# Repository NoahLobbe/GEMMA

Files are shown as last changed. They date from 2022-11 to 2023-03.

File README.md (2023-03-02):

# GEMMA
Gecko Electro-Mechanical Motion Attraction (or just 'Gecko')

This project was made for a robotics course, and is posted here as more of an archive so some stuff might not even work. Originally I designed it to have electromagnets in the ends of the legs powered by a L298N motor driver, but I ended up having to trash that idea; the L298N mounting is still present in final prototype though.

I have included .stl, .f3d (Fusion 360), and .ino (Arduino) files and also a short .pdf outlining its basic operation.

Youtube video: https://www.youtube.com/watch?v=VduDyxTGmJU

## Materials/Components:
- 3D print filament for body
- super glue (or equivalent) for battery packs and servo horns
- Lots of wires
- PCB 
- DC Barrel jack
- 5V regulator for power supply
- Female and Male headers
- 2 AA battery packs
- Arduino Uno
- 4 servos (SG90) (with accompanying servo horns)
- Ultrasonic sensor

### Code Note(s)
Smoothing code for servos I found from **James Bruton**:
- https://www.youtube.com/watch?v=jsXolwJskKM
- https://github.com/XRobots/ServoSmoothing

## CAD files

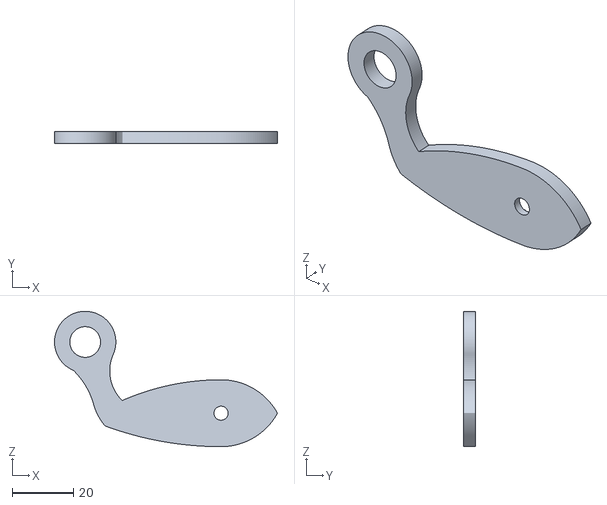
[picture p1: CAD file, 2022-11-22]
STLs/Leg - Right.stl
72.7 x 4.00 x 44.1

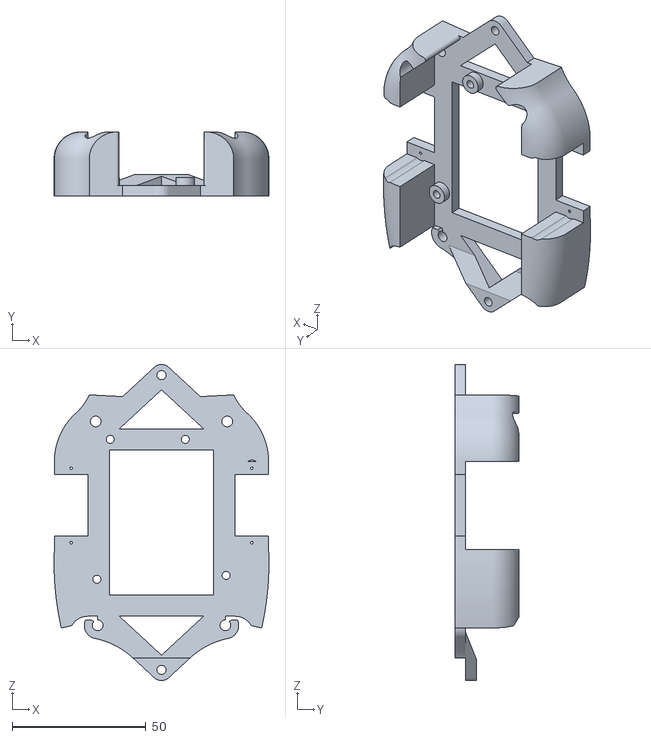
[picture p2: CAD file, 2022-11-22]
STLs/Arduino Base.stl
80.2 x 24.0 x 118.0

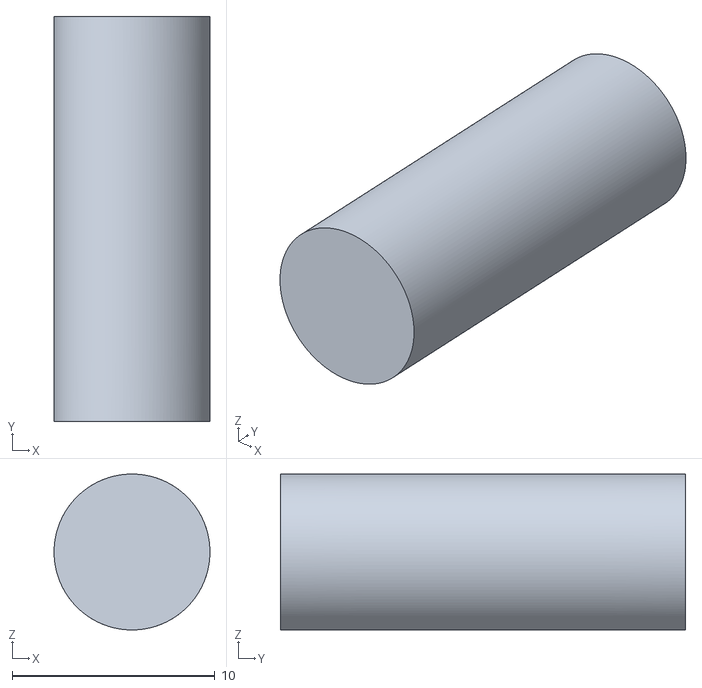
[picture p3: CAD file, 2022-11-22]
STLs/Head Pin.stl
7.70 x 20.0 x 7.70

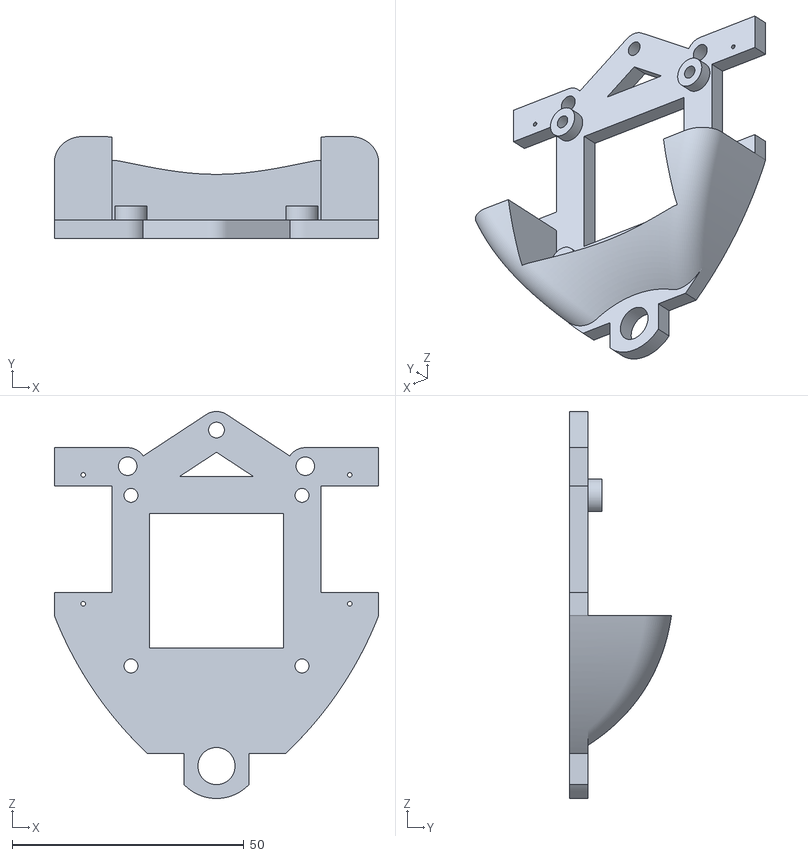
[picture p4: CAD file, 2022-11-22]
STLs/L298N Base.stl
70.0 x 22.0 x 83.5

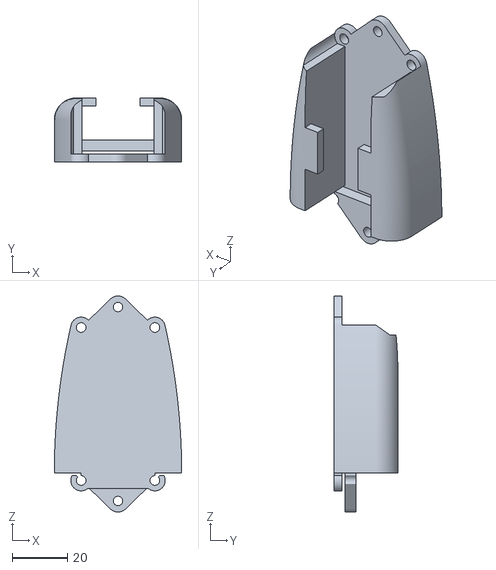
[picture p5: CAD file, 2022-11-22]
STLs/Tail (9V holder).stl
46.0 x 23.2 x 78.0

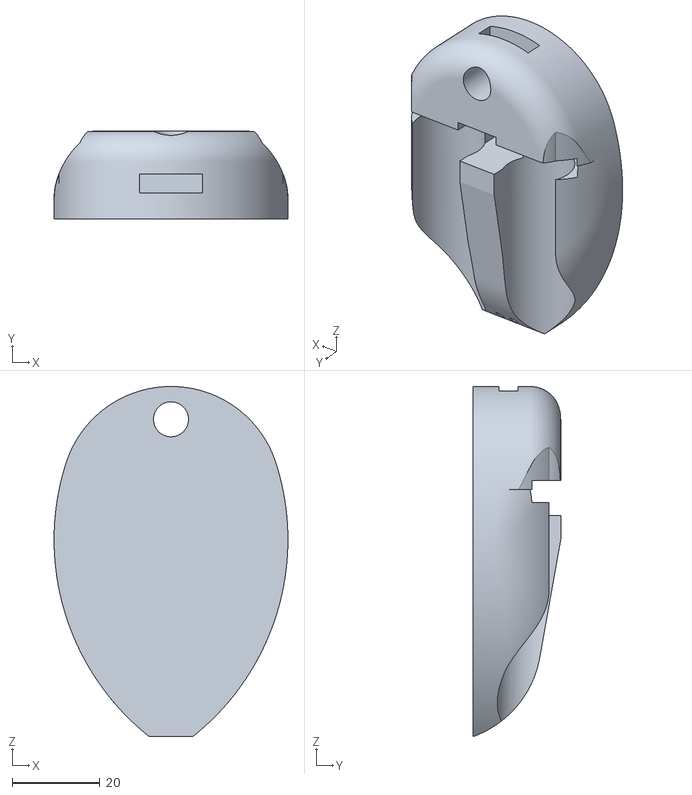
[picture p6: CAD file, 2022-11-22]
STLs/Head.stl
53.5 x 20.0 x 80.0

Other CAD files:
STLs/Leg - Left.stl
CAD/Arduino Base.f3d
CAD/Gecko - Major Product v35.f3z
CAD/Head Pin.f3d
CAD/Head.f3d
CAD/L298N Base.f3d
CAD/Leg - Left.f3d
CAD/Leg - Right.f3d
CAD/Tail (9V holder).f3d

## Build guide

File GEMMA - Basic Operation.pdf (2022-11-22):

# GEMMA

## Gecko Electro-Mechanical Motion Attraction

Made by Noah Lobbe for Stage 1 Robotic and Electronic Systems (Mechatronics)

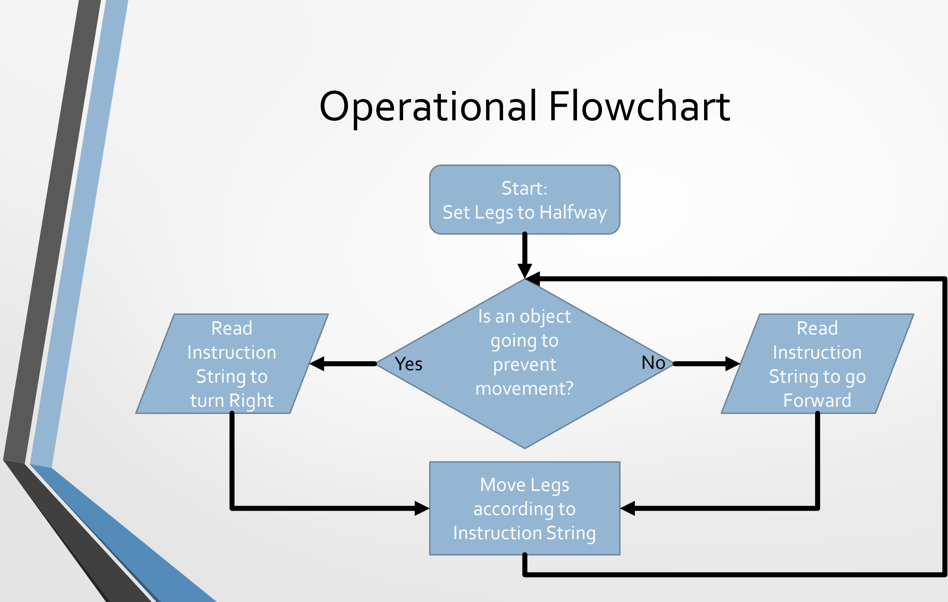
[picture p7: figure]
Operational Flowchart; Start: Set Legs to Halfway; Read Instruction String to go Forward; Is an object going to prevent movement?; Read Instruction String to turn Right; Move Legs according to Instruction String; Yes

# The Instruction String

## Each run through the flowchart, the Arduino reads 3 characters from a string in its code, which tells GEMMA what to do. The Instruction String for forward motion broken into 3-character chunks is: AGD LLU URU ULU AGD LRU ULU …which can be deciphered with the table of codes below:

Direction Code Letters | Group Leg Codes | Individual Leg Codes
U | Up | AGX | All Go X | LLX | LowerLeft go X
H | Halfway | FGX | Front Go X | LRX | LowerRight go X
D | Down | BGX | Back Go X | URX | UpperRight go X
| | LGX | Left Go X | ULX | UpperLeft go X
| | RGX | Right Go X
| | E.g., RGH = Right legs go Halfway | | E.g., URD = Upper Right leg go Down

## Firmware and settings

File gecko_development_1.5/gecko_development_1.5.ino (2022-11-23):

/*
 * GEMMA: Gecko Electro Mechanical Motion Atraction
 * 
 * ----Conventions----
 * constants: 'ALL_CAPS'
 * variables and class members: 'helpful_variable_name'
 * class names and objects: 'DoomButton' or 'Cheese'
 * 
 * by Noah Lobbe 
 * 
 * NOTES:
 * Thanks to James Bruton for his servo smoothing code: https://github.com/XRobots/ServoSmoothing and https://www.youtube.com/watch?v=jsXolwJskKM
 */

#include <Servo.h>


struct Limb {
  Servo Joint;
  float smoothed_angle;
  float prev_smoothed_angle;
  bool move_flag = true;
  char stage_flag = 'U'; //U=up, D=down, E=electromagnet, W=wait
};



////timing for main loop
unsigned long currentMillis;
long previousMillis = 0;    // set up timers
long interval = 5;        //ms time constant for timer


////Motion
 /* 3 letter motion commands
  * AGX = All Go X
  * FGX = Front Go X
  * BGX = Back Go X
  * LGX = Left Go X
  * RGX = Right Go X
  * 
  * DLX = Diagonal Left (\) Go X 
  * DRX = Diagonal Right (/) Go X
  * 
  * XXU = Up
  * XXH = Halfway
  * XXD = Down
  * 
  * LLX = LowerLeft go X
  * LRX = LowerRight go X
  * URX = UpperRight go X
  * ULX = UpperLeft go X
  */

const char straight_motion_array[] = { //best straight line 
  'A', 'G', 'D', 
  'L', 'L', 'U',
  'U', 'R', 'U',
  'U', 'L', 'U',
  'A', 'G', 'D',
  'L', 'R', 'U',
  'U', 'R', 'U',
  'U', 'L', 'U'
};

const char left_turn_motion_array[] = { //not currently used
  'A', 'G', 'D',
  'L', 'R', 'U',
  'U', 'R', 'U',
  'L', 'L', 'U'
};
const char right_turn_motion_array[] = { 
  'A', 'G', 'D',
  'L', 'L', 'U',
  'U', 'L', 'U',
  'L', 'R', 'U'
};

#define STRAIGHT_MOTION_LENGTH sizeof(straight_motion_array)/sizeof(straight_motion_array[0])
#define LEFT_TURN_MOTION_LENGTH sizeof(left_turn_motion_array)/sizeof(left_turn_motion_array[0])
#define RIGHT_TURN_MOTION_LENGTH sizeof(right_turn_motion_array)/sizeof(right_turn_motion_array[0])
int start_slice_index = 0;
int previous_start_slice_index = start_slice_index-1; //mustn't start the same as start_slice_index

String direction_flag = "FORWARD";
char limb_group; //eg AG = All legs
char limb_side; //eg LG = Left legs
char leg_direction; //eg AGU = 
String double_char_code; //becomes (String)limb_group + (String)limb_side; //cast chars to strings to prevent integer addition


////Servos variables and objects
//NOTE: position measurements are not neccessarily degrees, eg. 90 is half way for ServoObj.write(...) method even if a servo can only go to 80deg
#define SERVO_STARTING_POS 90 

//Lower Left Limb
#define SERVO_LL_MIN 30
#define SERVO_LL_MAX 140
#define SERVO_LL_HALF (SERVO_LL_MAX - SERVO_LL_MIN)/2
#define LOWER_LEFT_SERVO_PIN 2
#define LOWER_LEFT_EM_PIN 6 //L298N En_A -> Out_1
Limb LowerLeft;
int16_t servo_angle_input = SERVO_STARTING_POS;

//Lower Right Limb
#define SERVO_LR_MIN 155
#define SERVO_LR_MAX 45
#define SERVO_LR_HALF abs( (SERVO_LR_MAX - SERVO_LR_MIN)/2 )
#define LOWER_RIGHT_SERVO_PIN 3
#define LOWER_RIGHT_EM_PIN 7 //L298N En_B -> Out_2
Limb LowerRight;

//Upper Right Limb
#define SERVO_UR_MIN 125
#define SERVO_UR_MAX 20
#define SERVO_UR_HALF abs( (SERVO_UR_MAX - SERVO_UR_MIN)/2 )
#define UPPER_RIGHT_SERVO_PIN 4
#define UPPER_RIGHT_EM_PIN 8 //L298N En_C -> Out_3
Limb UpperRight;

//Upper Left Limb
#define SERVO_UL_MIN 40
#define SERVO_UL_MAX 130
#define SERVO_UL_HALF (SERVO_UL_MAX - SERVO_UL_MIN)/2
#define UPPER_LEFT_SERVO_PIN 5
#define UPPER_LEFT_EM_PIN 9 //L298N En_D -> Out_4
Limb UpperLeft;


////Ultrasonic sensor
#define TRIGGER 11
#define ECHO  12
#define speed_of_sound 340 //metres per second
uint8_t dist_sensor_time_counter = 0;

#define obstacle_distance_minimum 100 //mm
uint16_t obstacle_distance_mm;



void setup() {

  pinMode(TRIGGER, OUTPUT);
  pinMode(ECHO, INPUT);
  digitalWrite(TRIGGER, LOW);
  
  LowerLeft.Joint.attach(LOWER_LEFT_SERVO_PIN);
  LowerLeft.Joint.write(SERVO_STARTING_POS);//SERVO_LL_MIN);//
  LowerLeft.smoothed_angle = SERVO_STARTING_POS;
  LowerLeft.prev_smoothed_angle = LowerLeft.smoothed_angle; //to prevent leg from going down instantly
  
  LowerRight.Joint.attach(LOWER_RIGHT_SERVO_PIN);
  LowerRight.Joint.write(SERVO_STARTING_POS);
  LowerRight.smoothed_angle = SERVO_STARTING_POS;
  LowerRight.prev_smoothed_angle = LowerRight.smoothed_angle; //to prevent leg from going down instantly

  UpperRight.Joint.attach(UPPER_RIGHT_SERVO_PIN);
  UpperRight.Joint.write(SERVO_STARTING_POS);
  UpperRight.smoothed_angle = SERVO_STARTING_POS;
  UpperRight.prev_smoothed_angle = UpperRight.smoothed_angle; //to prevent leg from going down instantly

  UpperLeft.Joint.attach(UPPER_LEFT_SERVO_PIN);
  UpperLeft.Joint.write(SERVO_STARTING_POS);
  UpperLeft.smoothed_angle = SERVO_STARTING_POS;
  UpperLeft.prev_smoothed_angle = UpperLeft.smoothed_angle; //to prevent leg from going down instantly

 
  delay(2500);
}

void updateServoVal(Limb& limbObj, int angle_input) {
  limbObj.smoothed_angle = (angle_input * 0.04) + (limbObj.prev_smoothed_angle * 0.96);
  limbObj.prev_smoothed_angle = limbObj.smoothed_angle;

}

bool up(Limb& limbObj, int servo_target_angle, char side) {
  //returns true if finished going up
  if (side == 'L') {
    if (limbObj.Joint.read() >= servo_target_angle-1) { //rounding issue from Joint.smoothed_angle being float; when smoothed_angle=129.99 Joint.read() returns 129 instead of 130. Could check with smoothed_angle but a different might have been writen to servo; .read() prevents that
      return true;
    } else {
      updateServoVal(limbObj, servo_target_angle);
      return false;
    }
    
  } else if (side == 'R') {    
    if (limbObj.Joint.read() <= servo_target_angle) { 
      return true;
    } else {
     updateServoVal(limbObj, servo_target_angle);
     return false;
    }
  }
}

bool down(Limb& limbObj, int servo_target_angle, char side) {
  //returns true if finished going down
  if (side == 'L') {
    if (limbObj.Joint.read() <= servo_target_angle) { //servo.read() loses the decimal (from limbObj.smoothed_angle) e.g 129.9999 becomes 129 so if servo_max=130 then it won't ever succeed unless servo_max -=1
      return true;
    } else {
      updateServoVal(limbObj, servo_target_angle);
      return false;
    }
    
  } else if (side == 'R') {
    if (limbObj.Joint.read() >= servo_target_angle-1) { //rounding issue from Joint.smoothed_angle being float; when smoothed_angle=129.99 Joint.read() returns 129 instead of 130. Could check with smoothed_angle but a different might have been writen to servo; .read() prevents that
      return true;
    } else {
     updateServoVal(limbObj, servo_target_angle);
     return false;
    }
  }
}

bool updateLimb(char direction_char, Limb& limbObj, int up_angle, int down_angle, char side) {
  if (direction_char == 'U') {
    return up(limbObj, up_angle, side);
  } else if (direction_char == 'D') {
    return down(limbObj, down_angle, side);
  } else {//halfway
    return up(limbObj, 90, side);
  }
}

bool isLimb(String limb_code) {
  if ( (limb_code=="LL") || (limb_code=="LR") || (limb_code=="UR") || (limb_code=="UL") ) {
    return true;
  } else {
    return false;
  }
}

Limb& getLimb(String limb_code) {
  if (limb_code == "LL") {
    return LowerLeft;    
  } else if (limb_code == "LR") {
    return LowerRight;    
  } else if (limb_code == "UR") {
    return UpperRight;    
  } else if (limb_code == "UL") {
    return UpperLeft;
  }
}

int getServoMax(String limb_code) {
  if (limb_code == "LL") {
    return SERVO_LL_MAX;   
  } else if (limb_code == "LR") {
    return SERVO_LR_MAX;
  } else if (limb_code == "UR") {
    return SERVO_UR_MAX;
  } else if (limb_code == "UL") {
    return SERVO_UL_MAX;
  } else {
    return SERVO_STARTING_POS;
  }
}
int getServoMin(String limb_code) {
  if (limb_code == "LL") {
    return SERVO_LL_MIN;   
  } else if (limb_code == "LR") {
    return SERVO_LR_MIN;   
  } else if (limb_code == "UR") {
    return SERVO_UR_MIN;   
  } else if (limb_code == "UL") {
    return SERVO_UL_MIN;
  } else {
    return SERVO_STARTING_POS;
  }
}

void updateSliceIndex() {
  previous_start_slice_index = start_slice_index;
  start_slice_index += 3;

  int motion_array_length;
  if (direction_flag == "RIGHT") {
    motion_array_length = RIGHT_TURN_MOTION_LENGTH;
  } else { //forward
    motion_array_length = STRAIGHT_MOTION_LENGTH; 
  }
  
  if (start_slice_index >= motion_array_length) {
    start_slice_index =0 ;
  }
}


void loop(){

  currentMillis = millis();
  if (currentMillis - previousMillis >= interval) {  //timing loop
    
    //ultrasonic sensor
    uint16_t duration_uS; //uS = microseconds
    if (dist_sensor_time_counter >= 60/interval) { //eg. if interval = 10, then there only needs to be 6 passes to run this
      digitalWrite(TRIGGER, HIGH);
      delayMicroseconds(10); //send a 10uS trigger pulse
      digitalWrite(TRIGGER, LOW);
  
      duration_uS = pulseIn(ECHO, HIGH, 0);
      uint16_t obstacle_distance_mm = 0.5 * speed_of_sound * duration_uS * 1e-3;
    
      if (obstacle_distance_mm <= obstacle_distance_minimum) {
        direction_flag = "RIGHT";
      } else {
        direction_flag = "FORWARD";
      }
      dist_sensor_time_counter = 0; //reset
    }

    
    //determining limb movements
    if (previous_start_slice_index != start_slice_index) {
      
      if (direction_flag == "FORWARD") {
        limb_group = straight_motion_array[start_slice_index];
        limb_side = straight_motion_array[start_slice_index+1];
        leg_direction = straight_motion_array[start_slice_index+2];
        double_char_code = (String)limb_group + (String)limb_side; //cast chars to strings to prevent integer addition
        
      } else if (direction_flag == "RIGHT") {
        limb_group = right_turn_motion_array[start_slice_index];
        limb_side = right_turn_motion_array[start_slice_index+1];
        leg_direction = right_turn_motion_array[start_slice_index+2];
        double_char_code = (String)limb_group + (String)limb_side; //cast chars to strings to prevent integer addition
      }

    }
   
    //motion
    bool limb_movement_done; //servos don't finish their movement in one run (smoothing)
    if (isLimb(double_char_code)) {
      limb_movement_done = updateLimb(leg_direction, getLimb(double_char_code), getServoMax(double_char_code), getServoMin(double_char_code), limb_side);
      
    } else if (double_char_code == "AG") { //all limbs
      bool LL = updateLimb(leg_direction, LowerLeft, SERVO_LL_MAX, SERVO_LL_MIN, 'L');
      bool LR = updateLimb(leg_direction, LowerRight, SERVO_LR_MAX, SERVO_LR_MIN, 'R');
      bool UR = updateLimb(leg_direction, UpperRight, SERVO_UR_MAX, SERVO_UR_MIN, 'R');
      bool UL = updateLimb(leg_direction, UpperLeft, SERVO_UL_MAX, SERVO_UL_MIN, 'L');
      
      if (LL && LR && UR && UL) {
        limb_movement_done = true;
      } else {
        limb_movement_done = false;
      }
      
    } else if (double_char_code == "FG") { //front limbs
      bool UR = updateLimb(leg_direction, UpperRight, SERVO_UR_MAX, SERVO_UR_MIN, 'R');
      bool UL = updateLimb(leg_direction, UpperLeft, SERVO_UL_MAX, SERVO_UL_MIN, 'L');
      
      if ( UR && UL) {
        limb_movement_done = true;
      } else {
        limb_movement_done = false;
      }
      
    } else if (double_char_code == "BG") { //back limbs
      bool LL = updateLimb(leg_direction, LowerLeft, SERVO_LL_MAX, SERVO_LL_MIN, 'L');
      bool LR = updateLimb(leg_direction, LowerRight, SERVO_LR_MAX, SERVO_LR_MIN, 'R');
      
      if (LL && LR) {
        limb_movement_done = true;
      } else {
        limb_movement_done = false;
      }
      
    } else if (double_char_code == "LG") { //Left limbs
      bool LL = updateLimb(leg_direction, LowerLeft, SERVO_LL_MAX, SERVO_LL_MIN, 'L');
      bool UL = updateLimb(leg_direction, UpperLeft, SERVO_UL_MAX, SERVO_UL_MIN, 'L');
      
      if (LL && UL) {
        limb_movement_done = true;
      } else {
        limb_movement_done = false;
      }
      
    } else if (double_char_code == "RG") { //Right limbs
      bool LR = updateLimb(leg_direction, LowerRight, SERVO_LR_MAX, SERVO_LR_MIN, 'R');
      bool UR = updateLimb(leg_direction, UpperRight, SERVO_UR_MAX, SERVO_UR_MIN, 'R');
     
      if (LR && UR) {
        limb_movement_done = true;
      } else {
        limb_movement_done = false;
      }
      
    } else if (double_char_code == "DL") { //Diagonal Left (\)
      bool LR = updateLimb(leg_direction, LowerRight, SERVO_LR_MAX, SERVO_LR_MIN, 'R');
      bool UL = updateLimb(leg_direction, UpperLeft, SERVO_UL_MAX, SERVO_UL_MIN, 'L');
      
      if (LR && UL) {
        limb_movement_done = true;
      } else {
        limb_movement_done = false;
      }
      
    } else if (double_char_code == "DR") { //Diagonal Right (/)
      bool LL = updateLimb(leg_direction, LowerLeft, SERVO_LL_MAX, SERVO_LL_MIN, 'L');
      bool UR = updateLimb(leg_direction, UpperRight, SERVO_UR_MAX, SERVO_UR_MIN, 'R');
      
      if (LL && UR) {
        limb_movement_done = true;
      } else {
        limb_movement_done = false;
      }
      
    }

    //update servo positions
    LowerLeft.Joint.write(LowerLeft.smoothed_angle);
    LowerRight.Joint.write(LowerRight.smoothed_angle);
    UpperRight.Joint.write(UpperRight.smoothed_angle);
    UpperLeft.Joint.write(UpperLeft.smoothed_angle);
    
    //update variables
    previousMillis = currentMillis; 
    dist_sensor_time_counter++; 
    
    if (limb_movement_done) {
      updateSliceIndex(); //next run gets the next 3 instruction chars
    }
    
  } // end of main loop
  
}

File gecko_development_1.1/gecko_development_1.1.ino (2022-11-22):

/*
 * GEMMA: Gecko Electro Magnet Motion Atraction
 * A gecko that climbs up metal surfaces by using electromagnets as feet.
 * 
 * ----Conventions----
 * constants: 'ALL_CAPS'
 * variables and class members: 'helpful_variable_name'
 * class names and objects: 'DoomButton' or 'Cheese'
 * 
 * by Noah Lobbe 
 * 
 * NOTES:
 * Thanks to James Bruton for his servo smoothing code: https://github.com/XRobots/ServoSmoothing and https://www.youtube.com/watch?v=jsXolwJskKM
 */

#include <Servo.h>


class Electromagnet {
  public:
    Electromagnet(); //initialize
    void write(bool on_state);
    void attach(int pin);
    int pin;
    bool state;
};

Electromagnet::Electromagnet(){
}
void Electromagnet::attach(int _pin) {
  pin = _pin;
  pinMode(pin, OUTPUT);
}
void Electromagnet::write(bool on_state) {
  digitalWrite(pin, on_state);
  state = on_state;
}

struct Limb {
  Servo Joint;
  Electromagnet EM;
  float smoothed_angle;
  float prev_smoothed_angle;
};


////Misc.
#define speed_of_sound 340 //metres per second
#define len 100 
uint32_t values[len]; 
uint8_t counter = 0;

#define obstacle_distance_minimum 100 //mm
uint16_t obstacle_distance_mm; //mm

////timing for main loop
unsigned long currentMillis;
long previousMillis = 0;    // set up timers
long interval = 5;        //ms time constant for timer

////Motion
String current_leg_flag = "LL"; //LL->Lower Left, ..... Cycles in order: LL -> UR -> LR -> UL -> LL...
String current_leg_stage_flag = "UP"; //UP, EM, DOWN, DONE

////Servos variables and objects
//NOTE: position measurements are not neccessarily degrees, eg. 90 is half way for ServoObj.write(...) method even if a servo can only go to 80deg
#define SERVO_STARTING_POS 90 

//Lower Left Limb
#define SERVO_LL_MIN 30
#define SERVO_LL_MAX 140
#define SERVO_LL_HALF_POS (SERVO_LL_MAX - SERVO_LL_MIN)/2
#define LOWER_LEFT_SERVO_PIN 2
#define LOWER_LEFT_EM_PIN 6 //L298N En_A -> Out_1
Limb LowerLeft;
int16_t servo_angle_input = SERVO_STARTING_POS;

//Lower Right Limb
#define SERVO_LR_MIN 155
#define SERVO_LR_MAX 45
#define SERVO_LR_HALF_POS (SERVO_LR_MAX - SERVO_LR_MIN)/2
#define LOWER_RIGHT_SERVO_PIN 3
#define LOWER_RIGHT_EM_PIN 7 //L298N En_B -> Out_2
Limb LowerRight;

//Upper Right Limb
#define SERVO_UR_MIN 125
#define SERVO_UR_MAX 20
#define SERVO_UR_HALF_POS (SERVO_UR_MAX - SERVO_UR_MIN)/2
#define UPPER_RIGHT_SERVO_PIN 4
#define UPPER_RIGHT_EM_PIN 8 //L298N En_C -> Out_3
Limb UpperRight;

//Upper Left Limb
#define SERVO_UL_MIN 40
#define SERVO_UL_MAX 130
#define SERVO_UL_HALF_POS (SERVO_UL_MAX - SERVO_UL_MIN)/2
#define UPPER_LEFT_SERVO_PIN 5
#define UPPER_LEFT_EM_PIN 9 //L298N En_D -> Out_4
Limb UpperLeft;

/*
////Ultrasonic sensor
#define TRIGGER 11
#define ECHO  12

*/

String code;
int angle;

void setup() {
  Serial.begin(115200);

  /*
  pinMode(TRIGGER, OUTPUT);
  pinMode(ECHO, INPUT);
  digitalWrite(TRIGGER, LOW);
  */
  
  LowerLeft.Joint.attach(LOWER_LEFT_SERVO_PIN);
  LowerLeft.Joint.write(SERVO_STARTING_POS);
  LowerLeft.EM.attach(LOWER_LEFT_EM_PIN);
  //LowerLeft.EM.write(1);
  LowerLeft.smoothed_angle = SERVO_STARTING_POS;
  LowerLeft.prev_smoothed_angle = LowerLeft.smoothed_angle; //to prevent leg from going down instantly
  
  LowerRight.Joint.attach(LOWER_RIGHT_SERVO_PIN);
  LowerRight.Joint.write(SERVO_STARTING_POS);
  LowerRight.EM.attach(LOWER_RIGHT_EM_PIN);
  //LowerRight.EM.write(1);
  LowerRight.smoothed_angle = SERVO_STARTING_POS;
  LowerRight.prev_smoothed_angle = LowerRight.smoothed_angle; //to prevent leg from going down instantly

  UpperRight.Joint.attach(UPPER_RIGHT_SERVO_PIN);
  UpperRight.Joint.write(SERVO_STARTING_POS);
  UpperRight.EM.attach(UPPER_RIGHT_EM_PIN);
  //UpperRight.EM.write(1);
  UpperRight.smoothed_angle = SERVO_STARTING_POS;
  UpperRight.prev_smoothed_angle = UpperRight.smoothed_angle; //to prevent leg from going down instantly

  UpperLeft.Joint.attach(UPPER_LEFT_SERVO_PIN);
  UpperLeft.Joint.write(SERVO_STARTING_POS);
  UpperLeft.EM.attach(UPPER_LEFT_EM_PIN);
  //UpperLeft.EM.write(1);
  UpperLeft.smoothed_angle = SERVO_STARTING_POS;
  UpperLeft.prev_smoothed_angle = UpperLeft.smoothed_angle; //to prevent leg from going down instantly

  Serial.print("\nLowerLeft smoothed_angle ");
  Serial.print(LowerLeft.smoothed_angle);
  Serial.print(" LowerLeft prev_smoothed_angle ");
  Serial.print(LowerLeft.prev_smoothed_angle);
  
  Serial.print("\nLowerRight smoothed_angle ");
  Serial.print(LowerRight.smoothed_angle);
  Serial.print(" LowerRight prev_smoothed_angle ");
  Serial.print(LowerRight.prev_smoothed_angle);

  Serial.print("\nUpperRight smoothed_angle ");
  Serial.print(UpperRight.smoothed_angle);
  Serial.print(" UpperRight prev_smoothed_angle ");
  Serial.print(UpperRight.prev_smoothed_angle);

  Serial.print("\nUpperLeft smoothed_angle ");
  Serial.print(UpperLeft.smoothed_angle);
  Serial.print(" UpperLeft prev_smoothed_angle ");
  Serial.print(UpperLeft.prev_smoothed_angle);
  
  delay(2000);
  
}

void updateServoVal(Limb& limbObj, int angle_input) {
  limbObj.smoothed_angle = (angle_input * 0.04) + (limbObj.prev_smoothed_angle * 0.96);
  limbObj.prev_smoothed_angle = limbObj.smoothed_angle;

  Serial.print("\n smoothed angle INSIDE ");
 Serial.print(limbObj.smoothed_angle);
  Serial.print(" prev_smoothed_angle INSIDE ");
  Serial.print(limbObj.prev_smoothed_angle);
}

void updateLimb(Limb& limbObj, int servo_max, int servo_min, String next_leg_code, char side) {
  //'side' is required as the Right servos need to go in opposite direction to Left servos
  
  if (current_leg_stage_flag == "UP") {
    if (side == 'L') {
      if (limbObj.Joint.read() >= servo_max-1) { //servo.read() loses the decimal (from limbObj.smoothed_angle) e.g 129.9999 becomes 129 so if servo_max=130 then it won't ever succeed unless servo_max -=1
        current_leg_stage_flag = "EM";
      } else {
        updateServoVal(limbObj, servo_max);
      }
    } else if (side == 'R') {
      if (limbObj.Joint.read() <= servo_max) { 
        current_leg_stage_flag = "EM";
      } else {
        updateServoVal(limbObj, servo_max);
      }
    }
    
  } else if (current_leg_stage_flag == "EM") { 
    //turn on EM
    current_leg_stage_flag = "DOWN";
      
  } else if (current_leg_stage_flag == "DOWN") {
    if (side == 'L') {
      if (limbObj.Joint.read() <= servo_min) {
        current_leg_stage_flag = "DONE";
      } else {
        updateServoVal(limbObj, servo_min);
      }
    } else if (side == 'R') {
      Serial.print(limbObj.Joint.read());
      if (limbObj.Joint.read() >= servo_min-1) {//servo.read() loses the decimal (from limbObj.smoothed_angle) e.g 129.9999 becomes 129 so if servo_max=130 then it won't ever succeed unless servo_max -=1
        current_leg_stage_flag = "DONE";
      } else {
        updateServoVal(limbObj, servo_min);
      }
    }
    
  } else if (current_leg_stage_flag == "DONE") {
        current_leg_stage_flag = "UP";
        current_leg_flag = next_leg_code;
  }
  
}
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
